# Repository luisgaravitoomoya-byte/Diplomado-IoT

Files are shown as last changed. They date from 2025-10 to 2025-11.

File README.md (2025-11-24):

Este repositorio contiene el firmware para el microPython, los scripts de backend de python y la base de datos
para desarrollar un dispositivo wearable para detectar caidas y geolocalizar a personas mayores.
Tambien se presenta el modelo 3D usado para la carcasa del proyecto de un archivo solidworks, el archivo para la placa PCB y un PDF que muestra las pruebas que se realizaron para el proyecto.

El proyecto opera bajo una arquitectura de Edge Computing y Nube segura.
Los componentes requeridos son:
Raspberry Pi Pico W: Adquisición de sensores, procesamiento de algoritmos y gestion de Wi-Fi.
Sensor MPU-6050: Sensor dedicado a la deteccion de caidas. Usado en el algoritmo hibrido.
Modulo GPS NEO-M8L: Modulo usado para la geolocalizacion, ubicacion en tiempo real y la geocerca.

Respecto a servicios externos en la web es necesario tener una cuenta en HiveMQ, MongoDB, Ubidots,Make y Telegram.

Para el firmware de la Raspberry Pi Pico W se requiere que sea MicroPython. 

Las librerias necesarias que tienen que instalar son:
umqtt.simple.py: Cliente MQTT para la comunicacion con HiveMQ.
urequests.py: Para peticiones HTTP a Ubidots, Make y Telegram.
ntptime.py: Necesario para la sincronizacion horaria, con esto se realiza la conexion SSL/TLS.
mpu6050.py: Driver de la libreria para poder leer el sensor dedicado a las caidas.
micropyGPS.py: Driver de la libreria para el modulo GPS.

En la imagen llamada circuito se puede ver las conexiones de la raspberry pi pico w con los sensores.

Cambios importantes en el main.py
Se tienen que actualizar las credenciales de cada persona. 
Como ser el nombre de la red y su contrasena: WIFI_SSID y WIFI_PASSWORD
Las credenciales de HiveMQ: BROKER_HOST, MQTT_USERNAME, MQTT_PASSWORD
Las credenciales de Ubidots: UBIDOTS_TOKEN
La URL del webhook de Make: MAKE_WEBHOOK_URL
Las credenciales de Telegram: TELEGRAM_BOT_TOKEN y TELEGRAM_CHAT_ID
La configuracion de las coordenadas de la geocerca: HOME_LAT y HOME_LON

Para los scripts de Python de la Pc que son necesarios para la base de datos es necesario instalar las librerias para el suscriptor:
pip install paho-mqtt pymongo pandas

En MongoDb hay que configurar el acceso a la red, esto se realiza asegurando que el acceso este abierto mediante la siguiente IP: 0.0.0.0/0

Actualizar el MONGO_URI de ambos scripts de python.

De igual manera se presenta los planos de los modelos 3D

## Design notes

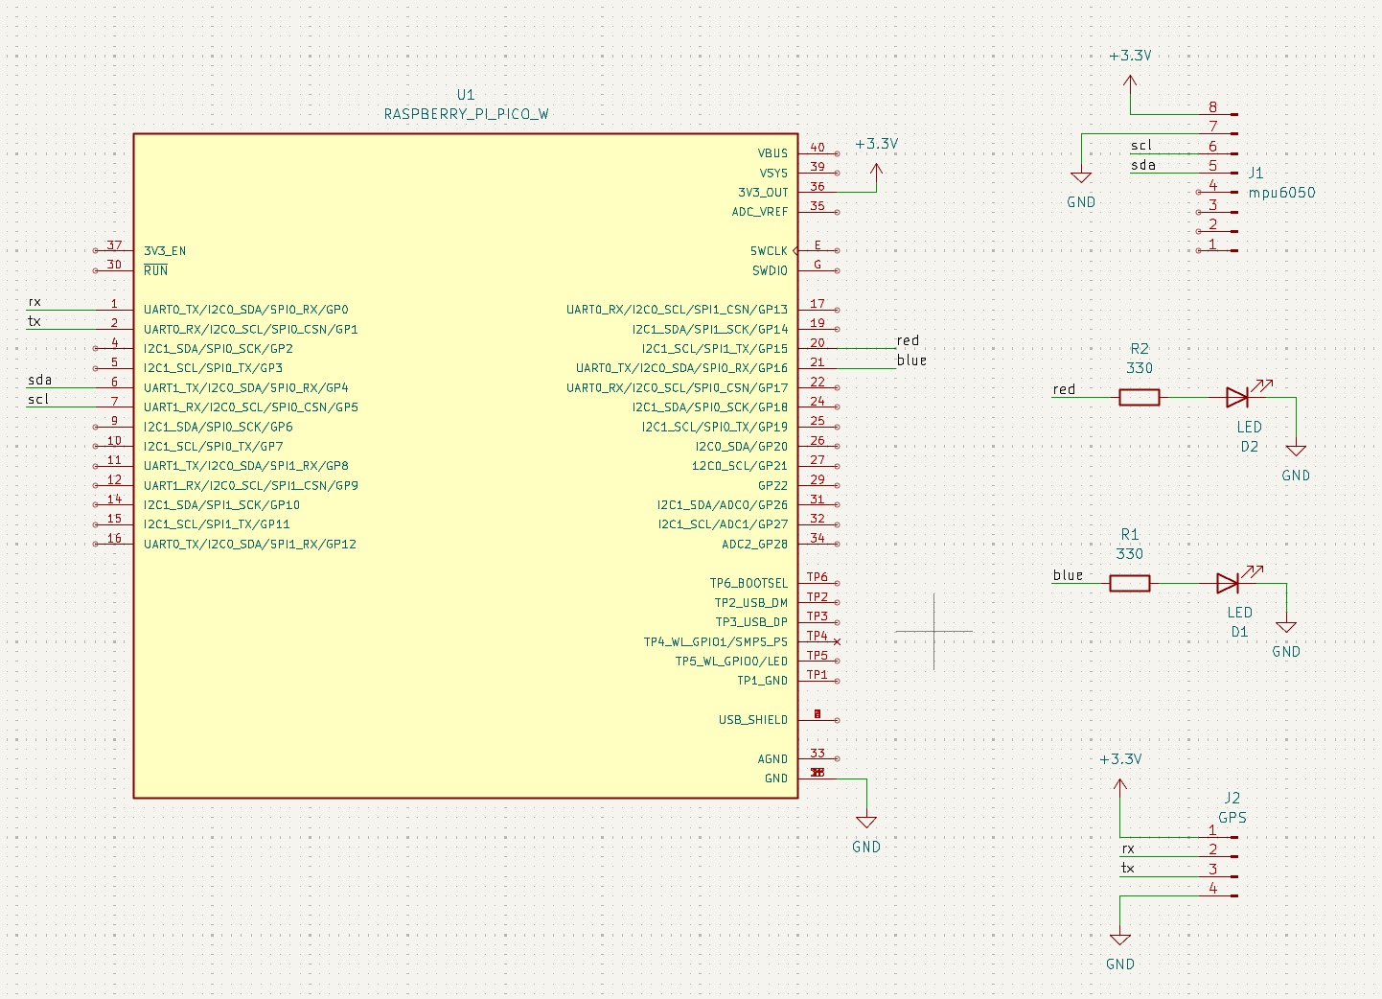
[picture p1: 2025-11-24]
Circuito.jpeg

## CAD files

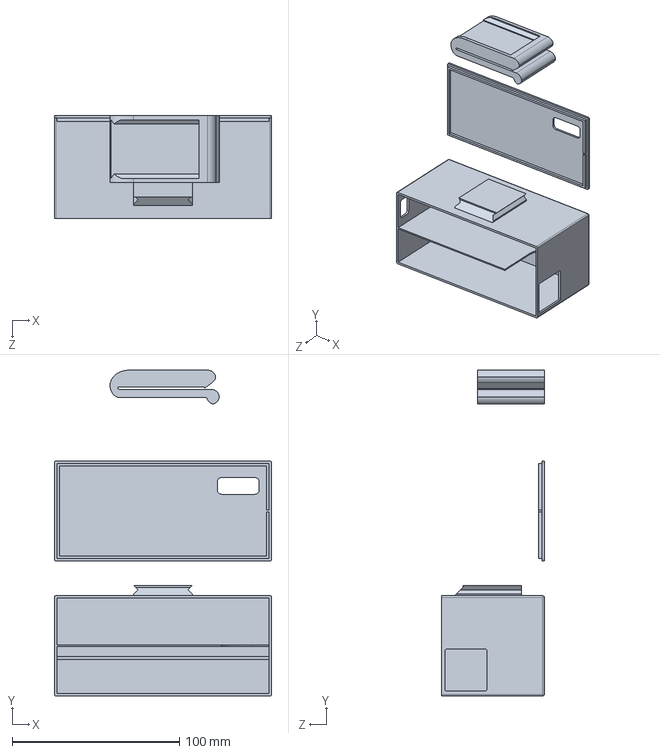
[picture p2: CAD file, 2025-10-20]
Wearable diplomado.SLDPRT
130.0 x 195.0 x 61.5 mm

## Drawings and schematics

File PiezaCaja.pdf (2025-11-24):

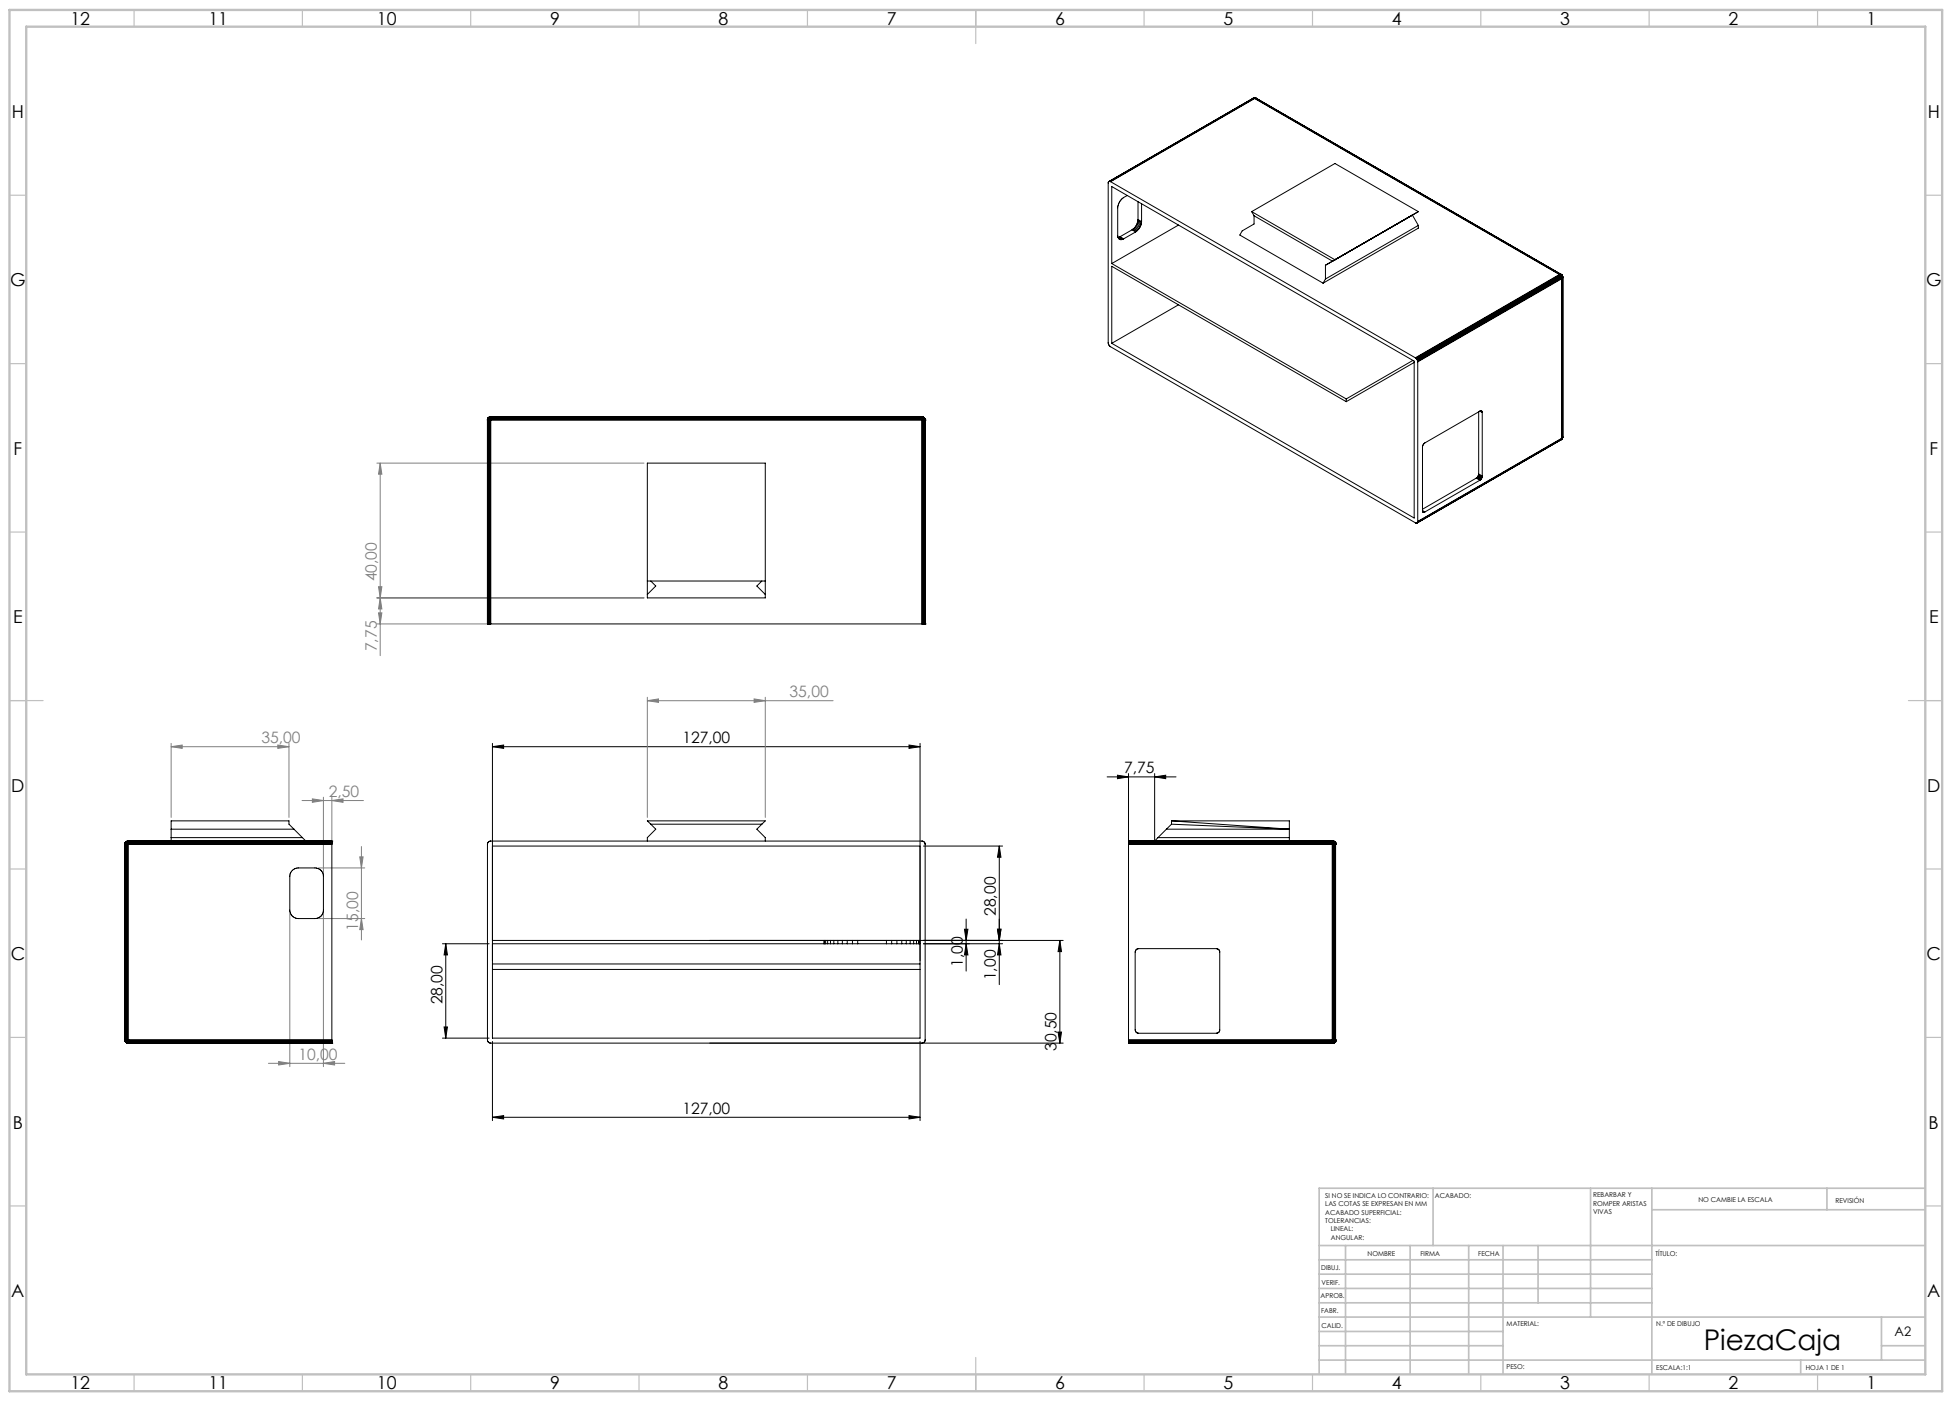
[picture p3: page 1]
ESCALA:1:1; HOJA 1 DE 1

SI NO SE INDICA LO CONTRARIO: LAS COTAS SE EXPRESAN EN MM ACABADO SUPERFICIAL: TOLERANCIAS: LINEAL: ANGULAR: | ACABADO: | REBARBAR Y ROMPER ARISTAS VIVAS | NO CAMBIE LA ESCALA | REVISIÓN

NOMBRE | FIRMA | FECHA | | | | TÍTULO:

DIBUJ.
VERIF.
APROB.
FABR.
CALID. | | | | MATERIAL: | N.º DE DIBUJO PiezaCaja | A2

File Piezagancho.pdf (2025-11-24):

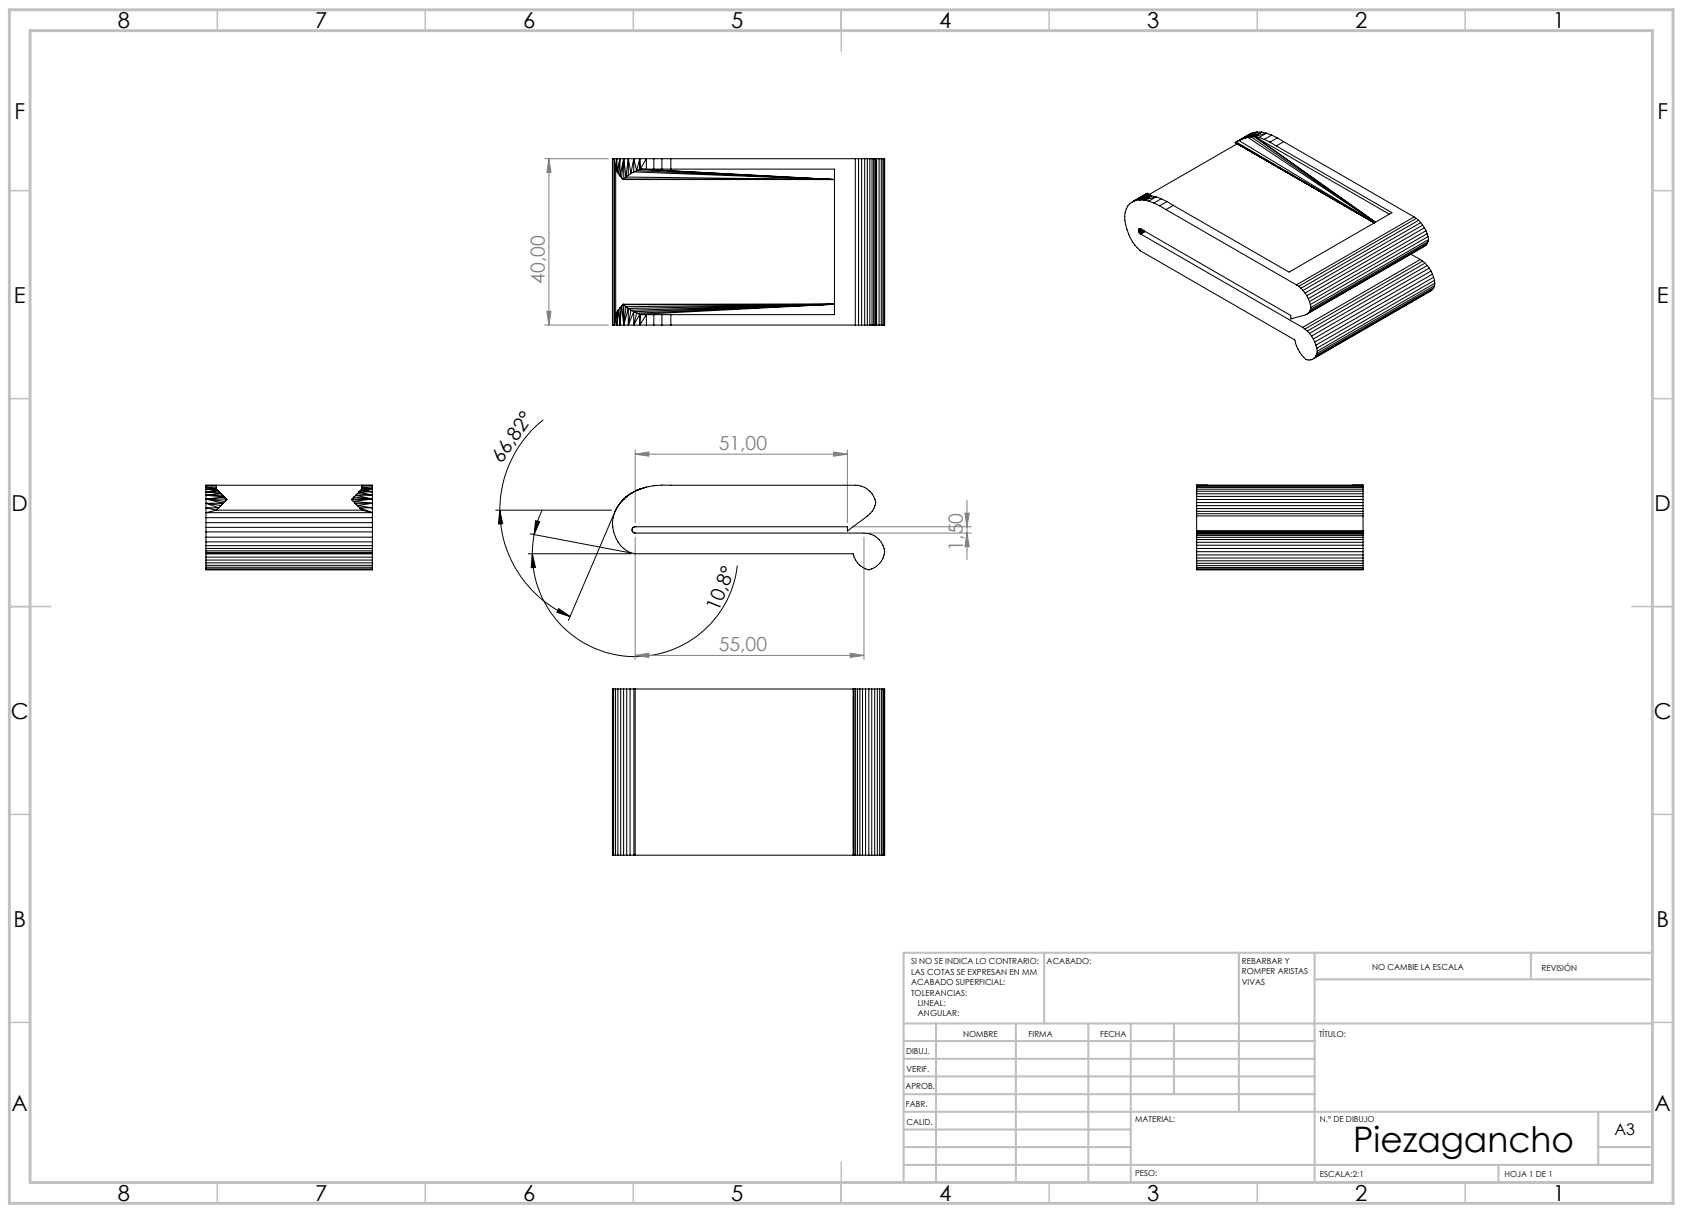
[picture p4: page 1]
ACABADO:; REBARBAR Y; ROMPER ARISTAS; NO CAMBIE LA ESCALA; REVISIÓN; ESCALA:2:1; HOJA 1 DE 1

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

NOMBRE | FIRMA | FECHA | | | | TÍTULO:

DIBUJ.
VERIF.
APROB.
FABR.
CALID. | | | | MATERIAL: | N.º DE DIBUJO Piezagancho | A3

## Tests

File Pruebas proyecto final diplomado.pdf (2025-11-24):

Registro de Pruebas Experimentales del Algoritmo Anticaídas

Este registro documenta el protocolo de validación y los resultados de las 100 caídas reales simuladas y 100 actividades cotidianas para evaluar la eficacia del algoritmo híbrido de detección de caídas, ejecutado en la Raspberry Pi Pico W.

Protocolo de Pruebas

El protocolo fue diseñado para simular escenarios de alto riesgo en la población objetivo (adultos mayores) y diferenciar caídas reales de movimientos cotidianos bruscos.

Las caídas reales simuladas fueron caídas controladas en distintas direcciones como ser hacia adelante, atrás o lateral. Le pondremos la etiqueta de CAÍDA.

Las actividades cotidianas son las acciones que uno realiza de manera normal como sentarse abruptamente, trotar, movimientos acelerados o tratar de levantar objetos. La etiqueta que se le dio es de AC.

El algoritmo de detección se consideró exitoso si se cumplía una de las siguientes condiciones:

- Verdadero positivo si hubiera una detección de CAÍDA en una simulación real.
- Verdadero negativo si hubiera una detección de NO CAÍDA en una actividad cotidiana (AC).

Las métricas críticas obtenidas son:

- Falso Negativo (FN): Caída real no detectada (4 eventos).
- Falso Positivo (FP): Alarma activada durante una AC (7 eventos).

Resultados

La siguiente tabla muestra un registro de las 100 pruebas de caídas como de actividades cotidianas.

No. | Escenario | Tiempo (ms) | Impacto Pico (G) | Algoritmo Detectó | Resultado Final

Caídas simuladas (1 - 100)

1 | Caída Lateral | 120 | 1.85 | SÍ | VP
2 | Caída | 150 | 2.51 | SÍ | VP

| Frontal
3 | Caída Trasera | 100 | 1.77 | SÍ | VP
4 | Caída Lateral | 90 | 1.62 | SÍ | VP
5 | Caída Frontal | 140 | 1.10 | SÍ | VP
6 | Caída Trasera | 105 | 0.75 | NO | FN (No Detectada)
7 | Caída Frontal | 130 | 1.30 | SÍ | VP
8 | Caída Lateral | 125 | 1.60 | SÍ | VP
9 | Caída Frontal | 145 | 1.95 | SÍ | VP
10 | Caída Trasera | 115 | 1.05 | SÍ | VP
11 | Caída Lateral | 110 | 1.90 | SÍ | VP
12 | Caída Frontal | 135 | 1.55 | SÍ | VP
13 | Caída Trasera | 120 | 1.80 | SÍ | VP
14 | Caída Lateral | 115 | 1.75 | SÍ | VP
15 | Caída Frontal | 100 | 1.20 | SÍ | VP
16 | Caída | 155 | 2.05 | SÍ | VP

| Trasera
17 | Caída Lateral | 130 | 1.45 | SÍ | VP
18 | Caída Frontal | 122 | 1.65 | SÍ | VP
19 | Caída Trasera | 108 | 1.15 | SÍ | VP
20 | Caída Lateral | 118 | 1.95 | SÍ | VP
21 | Caída Frontal | 142 | 1.40 | SÍ | VP
22 | Caída Trasera | 133 | 1.55 | SÍ | VP
23 | Caída Lateral | 105 | 1.18 | SÍ | VP
24 | Caída Frontal | 128 | 1.70 | SÍ | VP
25 | Caída Trasera | 112 | 1.09 | SÍ | VP
26 | Caída Lateral | 100 | 0.90 | NO | FN (No Detectada)
27 | Caída Frontal | 150 | 1.25 | SÍ | VP
28 | Caída Trasera | 110 | 1.50 | SÍ | VP
29 | Caída Lateral | 138 | 1.99 | SÍ | VP
30 | Caída | 115 | 1.60 | SÍ | VP

| Frontal
31 | Caída Trasera | 102 | 1.15 | SÍ | VP
32 | Caída Lateral | 145 | 1.40 | SÍ | VP
33 | Caída Frontal | 108 | 1.88 | SÍ | VP
34 | Caída Trasera | 130 | 1.70 | SÍ | VP
35 | Caída Lateral | 112 | 1.08 | SÍ | VP
36 | Caída Frontal | 148 | 1.99 | SÍ | VP
37 | Caída Trasera | 125 | 1.35 | SÍ | VP
38 | Caída Lateral | 104 | 1.20 | SÍ | VP
39 | Caída Frontal | 130 | 1.50 | SÍ | VP
40 | Caída Trasera | 111 | 1.65 | SÍ | VP
41 | Caída Lateral | 140 | 1.15 | SÍ | VP
42 | Caída Frontal | 120 | 1.70 | SÍ | VP
43 | Caída Trasera | 100 | 1.35 | SÍ | VP
44 | Caída | 135 | 0.95 | NO | FN (No

| Lateral | | | | Detectada)
45 | Caída Frontal | 145 | 1.99 | SÍ | VP
46 | Caída Trasera | 110 | 1.10 | SÍ | VP
47 | Caída Lateral | 120 | 0.95 | NO | FN (No Detectada)
48 | Caída Frontal | 130 | 1.70 | SÍ | VP
49 | Caída Trasera | 110 | 1.60 | SÍ | VP
50 | Caída Lateral | 105 | 1.20 | SÍ | VP
51 | Caída Frontal | 145 | 1.95 | SÍ | VP
52 | Caída Trasera | 115 | 1.05 | SÍ | VP
53 | Caída Lateral | 135 | 1.70 | SÍ | VP
54 | Caída Frontal | 11 5 | 0 1 . 2 | SÍ | VP
55 | Caída Trasera | 120 | 1.80 | SÍ | VP
56 | Caída Lateral | 115 | 1.75 | SÍ | VP
57 | Caída Frontal | 100 | 1.20 | SÍ | VP
58 | Caída | 155 | 2.05 | SÍ | VP

| Trasera
59 | Caída Lateral | 130 | 1.45 | SÍ | VP
60 | Caída Frontal | 122 | 1.65 | SÍ | VP
61 | Caída Trasera | 108 | 1.15 | SÍ | VP
62 | Caída Lateral | 118 | 1.95 | SÍ | VP
63 | Caída Frontal | 142 | 1.40 | SÍ | VP
64 | Caída Trasera | 133 | 1.55 | SÍ | VP
65 | Caída Lateral | 105 | 1.18 | SÍ | VP
66 | Caída Frontal | 128 | 1.70 | SÍ | VP
67 | Caída Trasera | 112 | 1.09 | SÍ | VP
68 | Caída Lateral | 100 | 0.90 | NO | FN (No Detectada)
69 | Caída Frontal | 150 | 1.25 | SÍ | VP
70 | Caída Trasera | 110 | 1.50 | SÍ | VP
71 | Caída Lateral | 138 | 1.99 | SÍ | VP
72 | Caída | 115 | 1.60 | SÍ | VP

| Frontal
73 | Caída Trasera | 102 | 1.15 | SÍ | VP
74 | Caída Lateral | 145 | 1.40 | SÍ | VP
75 | Caída Frontal | 108 | 1.88 | SÍ | VP
76 | Caída Trasera | 130 | 1.70 | SÍ | VP
77 | Caída Lateral | 112 | 1.08 | SÍ | VP
78 | Caída Frontal | 148 | 1.99 | SÍ | VP
79 | Caída Trasera | 125 | 1.35 | SÍ | VP
80 | Caída Lateral | 104 | 1.20 | SÍ | VP
81 | Caída Frontal | 130 | 1.50 | SÍ | VP
82 | Caída Trasera | 111 | 1.65 | SÍ | VP
83 | Caída Lateral | 140 | 1.15 | SÍ | VP
84 | Caída Frontal | 120 | 1.70 | SÍ | VP
85 | Caída Trasera | 100 | 1.35 | SÍ | VP
86 | Caída | 135 | 1.50 | SÍ | VP

| Lateral
87 | Caída Frontal | 145 | 1.99 | SÍ | VP
88 | Caída Trasera | 110 | 1.10 | SÍ | VP
89 | Caída Lateral | 120 | 1 .10 | SÍ | VP
90 | Caída Frontal | 130 | 1.70 | SÍ | VP
91 | Caída Trasera | 110 | 1.60 | SÍ | VP
92 | Caída Lateral | 105 | 1.20 | SÍ | VP
93 | Caída Frontal | 145 | 1.95 | SÍ | VP
94 | Caída Trasera | 115 | 1.05 | SÍ | VP
95 | Caída Lateral | 135 | 1.70 | SÍ | VP
96 | Caída Frontal | 110 | 0.90 | NO | FN (No Detectada)
97 | Caída Trasera | 120 | 1.80 | SÍ | VP
98 | Caída Lateral | 115 | 1.75 | SÍ | VP
99 | Caída Frontal | 100 | 1.20 | SÍ | VP
100 | Caída | 155 | 2.05 | SÍ | VP

| Trasera

Actividades cotidianas (101 - 200)

101 | AC: Sentarse Rápido | N/A | 1.35 | NO | VN
102 | AC: Tropezón Leve | 80 | 1.10 | NO | VN
103 | AC: Agacharse | N/A | 0.95 | NO | VN
104 | AC: Sentarse Brusco | N/A | 1.25 | NO | VN
105 | AC: Correr/Fren ar | N/A | 2.15 | SÍ | FP (Falsa Alarma)
106 | AC: Toser Fuerte | N/A | 1.08 | NO | VN
107 | AC: Levantar Objeto | N/A | 0.75 | NO | VN
108 | AC: Sentarse Brusco | N/A | 1.15 | NO | VN
109 | AC: Agacharse | N/A | 0.88 | NO | VN
110 | AC: Toser Fuerte | N/A | 1.20 | NO | VN

111 | A C: Trote Ligero | N/A | 1.25 | NO | VN
112 | A C: Agacharse | N/A | 0.65 | NO | VN
113 | A C: Correr/Fren ar | N/A | 1.30 | NO | VN
114 | A C: Levantar Objeto | N/A | 0.70 | NO | VN
115 | A C: Sentarse Rápido | N/A | 1.30 | NO | VN
116 | A C: Tropezón Leve | 70 | 1.05 | NO | VN
117 | A C: Agacharse | N/A | 0.85 | NO | VN
118 | A C: Sentarse Brusco | N/A | 1.45 | SÍ | FP (Falsa Alarma)
119 | A C: Correr/Fren ar | N/A | 2.50 | SÍ | FP (Falsa Alarma)
120 | A C: Toser Fuerte | N/A | 1.12 | NO | VN
121 | A C: Levantar Objeto | N/A | 0.60 | NO | VN
122 | A C: Sentarse | N/A | 1.10 | NO | VN

| Brusco
123 | A C: Agacharse | N/A | 0.80 | NO | VN
124 | A C: Toser Fuerte | N/A | 1.05 | NO | VN
125 | A C: Sentarse Rápido | N/A | 1.00 | NO | VN
126 | A C: Tropezón Leve | 65 | 1.20 | NO | VN
127 | A C: Agacharse | N/A | 0.90 | NO | VN
128 | A C: Sentarse Brusco | N/A | 0.85 | NO | VN
129 | A C: Correr/Fren ar | N/A | 1.08 | NO | VN
130 | A C: Toser Fuerte | N/A | 1.00 | NO | VN
131 | A C: Levantar Objeto | N/A | 0.70 | NO | VN
132 | A C: Sentarse Brusco | N/A | 1.18 | NO | VN
133 | A C: Agacharse | N/A | 0.88 | NO | VN
134 | A C: Toser | N/A | 1.25 | NO | VN

| Fuerte
135 | A C: Sentarse Rápido | N/A | 1.30 | NO | VN
136 | A C: Tropezón Leve | 75 | 1.15 | NO | VN
137 | A C: Agacharse | N/A | 0.70 | NO | VN
138 | A C: Sentarse Brusco | N/A | 1.40 | SÍ | FP (Falsa Alarma)
139 | A C: Correr/Fren ar | N/A | 1.20 | NO | VN
140 | A C: Toser Fuerte | N/A | 1.05 | NO | VN
141 | A C: Levantar Objeto | N/A | 0.65 | NO | VN
142 | A C: Sentarse Brusco | N/A | 1.20 | NO | VN
143 | A C: Agacharse | N/A | 0.80 | NO | VN
144 | A C: Toser Fuerte | N/A | 1.35 | NO | VN
145 | A C: Sentarse Rápido | N/A | 1.50 | SÍ | FP (Falsa Alarma)

146 | A C: Tropezón Leve | 85 | 1.10 | NO | VN
147 | A C: Agacharse | N/A | 0.95 | NO | VN
148 | A C: Sentarse Brusco | N/A | 1.28 | NO | VN
149 | A C: Correr/Fren ar | N/A | 0.65 | NO | VN
150 | A C: Toser Fuerte | N/A | 1.18 | NO | VN
151 | A C: Levantar Objeto | N/A | 0.55 | NO | VN
152 | A C: Sentarse Brusco | N/A | 1.12 | NO | VN
153 | A C: Agacharse | N/A | 0.85 | NO | VN
154 | A C: Toser Fuerte | N/A | 1.30 | NO | VN
155 | A C: Sentarse Rápido | N/A | 1.55 | SÍ | FP (Falsa Alarma)
156 | A C: Tropezón Leve | 90 | 1.25 | NO | VN
157 | A C: Agacharse | N/A | 0.75 | NO | VN

158 | A C: Sentarse Brusco | N/A | 1.12 | NO | VN
159 | A C: Correr/Fren ar | N/A | 0.9 | NO | VN
160 | A C: Toser Fuerte | N/A | 1.10 | NO | VN
161 | A C: Levantar Objeto | N/A | 0.65 | NO | VN
162 | A C: Sentarse Brusco | N/A | 1.22 | NO | VN
163 | A C: Agacharse | N/A | 0.88 | NO | VN
164 | A C: Toser Fuerte | N/A | 1.45 | NO | VN
165 | A C: Sentarse Rápido | N/A | 1.17 | NO | VN
166 | A C: Tropezón Leve | 80 | 1.20 | NO | VN
167 | A C: Agacharse | N/A | 0.72 | NO | VN
168 | A C: Sentarse Brusco | N/A | 1.05 | NO | VN
169 | A C: Correr/Fren | N/A | 0.95 | NO | VN

| ar
170 | A C: Toser Fuerte | N/A | 1.05 | NO | VN
171 | A C: Levantar Objeto | N/A | 0.50 | NO | VN
172 | A C: Sentarse Brusco | N/A | 1.10 | NO | VN
173 | A C: Agacharse | N/A | 0.80 | NO | VN
174 | A C: Toser Fuerte | N/A | 1.25 | NO | VN
175 | A C: Sentarse Rápido | N/A | 1.30 | NO | VN
176 | A C: Tropezón Leve | 75 | 1.18 | NO | VN
177 | A C: Agacharse | N/A | 0.90 | NO | VN
178 | A C: Sentarse Brusco | N/A | 1.55 | SÍ | FP (Falsa Alarma)
179 | A C: Correr/Fren ar | N/A | 0.85 | NO | VN
180 | A C: Toser Fuerte | N/A | 1.00 | NO | VN
181 | A C: | N/A | 0.60 | NO | VN

| Levantar Objeto
182 | A C: Sentarse Brusco | N/A | 1.25 | NO | VN
183 | A C: Agacharse | N/A | 0.75 | NO | VN
184 | A C: Toser Fuerte | N/A | 1.35 | NO | VN
185 | A C: Sentarse Rápido | N/A | 1.15 | NO | VN
186 | A C: Tropezón Leve | 85 | 1.05 | NO | VN
187 | A C: Agacharse | N/A | 0.98 | NO | VN
188 | A C: Sentarse Brusco | N/A | 1.15 | NO | VN
189 | A C: Correr/Fren ar | N/A | 1.30 | NO | VN
190 | A C: Toser Fuerte | N/A | 1.10 | NO | VN
191 | A C: Levantar Objeto | N/A | 0.55 | NO | VN
192 | A C: Sentarse Brusco | N/A | 1.20 | NO | VN

193 | A C: Agacharse | N/A | 0.70 | NO | VN
194 | A C: Toser Fuerte | N/A | 1.25 | NO | VN
195 | A C: Sentarse Rápido | N/A | 1.15 | NO | VN
196 | A C: Tropezón Leve | 80 | 1.10 | NO | VN
197 | A C: Agacharse | N/A | 0.90 | NO | VN
198 | A C: Sentarse Brusco | N/A | 1.30 | NO | VN
199 | A C: Correr/Fren ar | N/A | 1.25 | NO | VN
200 | A C: Toser Fuerte | N/A | 1.00 | NO | VN

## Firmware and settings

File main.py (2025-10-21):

from machine import UART, Pin, I2C
import utime
import network
from micropyGPS import MicropyGPS
import urequests
import math
import ujson
import usocket as socket
import ssl
import random 
import ntptime 


try:
    from umqtt.simple import MQTTClient
except ImportError:
    print("ADVERTENCIA: No se encontró la librería umqtt.simple. La alerta MQTT estará deshabilitada.")
    MQTTClient = None

try:
    from mpu6050 import MPU6050
except ImportError:
    print("ADVERTENCIA: No se encontró la librería mpu6050.py. La detección de caídas estará deshabilitada.")
    MPU6050 = None 


#CONFIGURACIÓN DEL SISTEMA Y CREDENCIALES 

#Credenciales de Wi-Fi
WIFI_SSID = "red wifi"        
WIFI_PASSWORD = "contraseña de wifi"

#Credenciales de Ubidots y Make
HTTP_SERVER = "industrial.api.ubidots.com"
UBIDOTS_DEVICE_LABEL = "gpspico"
UBIDOTS_TOKEN = "toke de ubidots" 
HTTP_PUBLISH_URL = f"http://{HTTP_SERVER}/api/v1.6/devices/{UBIDOTS_DEVICE_LABEL}"

#URL DE TU WEBHOOK DE MAKE (Geocerca)
MAKE_WEBHOOK_URL = "URL de Make" 

#Credenciales de TELEGRAM
TELEGRAM_BOT_TOKEN = "token de telegram" 
TELEGRAM_CHAT_ID = "ID del chat de telegram" 

#Configuración de Geocerca
HOME_LAT = -16.513800  
HOME_LON = -68.126000  
SAFE_RADIUS_M = 150    

#Configuración del MPU-6050
I2C_SDA_PIN = 4
I2C_SCL_PIN = 5
I2C_FREQ = 400000 

#(Detección Híbrida: Caída Libre + Alto Impacto)
MPU_THRESHOLD_G = 0.7    # Inicia la detección si Acel. < 0.7 G.
DURATION_MS = 100        # Captura caídas rápidas (100ms)
IMPACT_THRESHOLD_G = 1.05    # Mínimo impacto para confirmar la caída libre.
INTERRUPT_THRESHOLD_G = 0.85 # Hysteresis para detener la cuenta de Caída Libre.
INSTANT_IMPACT_G = 2.2     # Si Acel. > 2.2 G, activa la alerta inmediatamente.
FALL_COOLDOWN_MS = 15000   # Cooldown de 15 segundos.

# Configuración de GPS
FORCE_NEGATIVE_LAT = True 
FORCE_NEGATIVE_LON = True 
GPS_UART = UART(0, baudrate=9600, tx=Pin(0), rx=Pin(1))
my_gps = MicropyGPS(location_formatting='dd') 


#CONFIGURACIÓN DEL BROKER PRIVADO MQTT

BROKER_HOST = "URL HiveMW" 
BROKER_PORT = 8883  
MQTT_CLIENT_ID = f"pico_w_tracker_{random.getrandbits(16)}" 
MQTT_USERNAME = "usuario" 
MQTT_PASSWORD = "contraseña" 
MQTT_TOPIC_FALL = "rastreador/alerta/caida" 

#CONFIGURACIÓN DEL LED DE ESTADO
LED_PIN = Pin("LED", Pin.OUT)
LED_STATE = False


# Variables de estado globales
last_valid_lat = None
last_valid_lon = None
mpu_sensor = None 
fall_start_time = 0 
last_fall_time = 0 
last_debug_time_ms = 0
DEBUG_INTERVAL_MS = 1000
wifi_is_connected = False
mqtt_client = None 


#FUNCIONES DE UTILIDAD Y CONEXIÓN


def toggle_led():
    """Alterna el estado del LED (para el parpadeo)."""
    global LED_STATE
    LED_STATE = not LED_STATE
    LED_PIN.value(LED_STATE)

def set_led_solid_on():
    """Mantiene el LED encendido de forma fija."""
    global LED_STATE
    LED_STATE = True
    LED_PIN.value(LED_STATE)

def set_led_off():
    """Mantiene el LED apagado."""
    global LED_STATE
    LED_STATE = False
    LED_PIN.value(LED_STATE)


def set_time_ntp():
    """Sincroniza el reloj interno de la Pico W con un servidor NTP. Crucial para TLS/SSL."""
    global wifi_is_connected
    if not wifi_is_connected:
        print("[NTP] Omite la sincronización: No hay Wi-Fi.")
        return False
    
    print("[NTP] Sincronizando hora...")
    try:
        ntptime.settime()
        (year, month, day, hour, minute, second, _, _) = utime.localtime()
        print(f"[NTP] Hora sincronizada: {day}/{month}/{year} {hour}:{minute:02d}:{second:02d} UTC")
        return True
    except Exception as e:
        print(f"[NTP] Fallo al sincronizar la hora: {e}. La conexión MQTT podría fallar.")
        return False

def calculate_distance(lat1, lon1, lat2, lon2):
    """Calcula la distancia Haversine entre dos puntos GPS en metros."""
    R = 6371000 
    phi1 = math.radians(lat1)
    phi2 = math.radians(lat2)
    delta_phi = math.radians(lat2 - lat1)
    delta_lambda = math.radians(lon2 - lon1)

    a = math.sin(delta_phi / 2) * math.sin(delta_phi / 2) + \
        math.cos(phi1) * math.cos(phi2) * \
        math.sin(delta_lambda / 2) * math.sin(delta_lambda / 2)
        
    c = 2 * math.atan2(math.sqrt(a), math.sqrt(1 - a))
    
    distance_m = R * c
    return distance_m

def do_connect(ssid, password):
    """Maneja la conexión a la red Wi-Fi."""
    global wifi_is_connected
    wlan = network.WLAN(network.STA_IF)
    wlan.active(True)
    
    if wlan.isconnected():
        wifi_is_connected = True
        return True
    
    print('\n[WIFI] Conectando a la red...')
    wlan.connect(ssid, password)
    timeout = 10
    while not wlan.isconnected() and timeout > 0:
        toggle_led()
        print('.', end='')
        utime.sleep(1)
        timeout -= 1
        
    if wlan.isconnected():
        print('\n[WIFI] Conectado. IP:', wlan.ifconfig()[0])
        wifi_is_connected = True
        return True
    else:
        print('\n[WIFI] Falló la conexión.')
        wifi_is_connected = False
        return False

def initialize_mpu():
    """Inicializa el bus I2C y el sensor MPU-6050."""
    global mpu_sensor
    if MPU6050 is None: 
        print("[MPU] Inicialización omitida (librería mpu6050.py no encontrada).")
        return False
    
    print(f'[MPU] Inicializando I2C en SDA=GP{I2C_SDA_PIN}, SCL=GP{I2C_SCL_PIN}')
    try:
        i2c_bus = I2C(0, scl=Pin(I2C_SCL_PIN), sda=Pin(I2C_SDA_PIN), freq=I2C_FREQ)
        devices = i2c_bus.scan()
        if MPU6050.I2C_ADDR not in devices:
            print("ERROR: MPU-6050 no encontrado en la dirección I2C. Sistema anticaídas DESHABILITADO.")
            return False
            
        mpu_sensor = MPU6050(i2c_bus)
        _ = mpu_sensor.get_accel_data() 
        print("MPU-6050 detectado e inicializado. Sistema anticaídas ACTIVO.")
        return True
    except Exception as e:
        print(f"ERROR al inicializar MPU por excepción: {e}. Sistema anticaídas DESHABILITADO.")
        return False


#FUNCIONES DE CONEXIÓN Y ALERTA MQTT
#

def mqtt_connect_secure():
    if MQTTClient is None:
        return None

    try:
        ssl_params = {"server_hostname": BROKER_HOST}
        
        client = MQTTClient(
            client_id=MQTT_CLIENT_ID, 
            server=BROKER_HOST, 
            user=MQTT_USERNAME, 
            password=MQTT_PASSWORD,
            port=BROKER_PORT,
            ssl=True, 
            ssl_params=ssl_params, 
            keepalive=60
        )
        
        print(f"[MQTT] Intentando conectar a {BROKER_HOST}:{BROKER_PORT}...")
        connect_timeout = 10
        while connect_timeout > 0:
            try:
                client.connect()
                print(f"[MQTT] Conectado al broker seguro. ID: {MQTT_CLIENT_ID}")
                return client
            except OSError as e:
                toggle_led() 
                print('.', end='')
                utime.sleep(1)
                connect_timeout -= 1
        
        print(f"[MQTT] Falló la conexión segura al broker después de {10} segundos.")
        return None

    except Exception as e:
        print(f"[MQTT] ERROR de conexión segura al broker: {type(e).__name__}: {e}")
        return None

def send_mqtt_fall_alert(accel_magnitude, lat, lon): 
    global mqtt_client 

    if mqtt_client is None:
        print("[MQTT] Cliente no inicializado. Alerta MQTT omitida.")
        return

    try:
        payload_data = {
            "timestamp": utime.time(),
            "event": "CRITICAL_FALL",
            "impact_G": accel_magnitude,
            "device_id": MQTT_CLIENT_ID,
            "location": {"lat": lat, "lon": lon}
        }
        
        payload_json = ujson.dumps(payload_data)
        
        print("-" * 50)
        print(f"[MQTT] Intentando publicar en tópico: {MQTT_TOPIC_FALL}")
        print(f"[MQTT] Payload JSON: {payload_json}")
        print("-" * 50)
        
        mqtt_client.publish(MQTT_TOPIC_FALL, payload_json.encode('utf-8'))
        print(f"[MQTT] Publicada alerta de caída.")

    except Exception as e:
        print(f"[MQTT] Error CRÍTICO al publicar la alerta: {type(e).__name__}: {e}. Intentando reconectar...")
        
        try:
            mqtt_client.disconnect()
        except:
            pass
        mqtt_client = mqtt_connect_secure() 



#FUNCIONES DE ALERTA Y LÓGICA DE CAÍDA

def send_telegram_alert(lat, lon, is_fall_alert=False):
    """
    Envía alertas a Telegram (Geocerca o Caída).
    """
    if not do_connect(WIFI_SSID, WIFI_PASSWORD):
        print("[TELEGRAM] ERROR: No se pudo reconectar al Wi-Fi. Alerta de Telegram fallida.")
        return
        
    maps_link = f"https://www.google.com/maps?q={lat:.6f},{lon:.6f}"
    
    if is_fall_alert:
        subject = "¡ALERTA CRÍTICA: CAÍDA DETECTADA!"
        body = "Se ha detectado una caída fuerte. ¡Verifique el estado del paciente inmediatamente!"
    else:
        subject = "¡ALERTA DE GEOCERCA!"
        body = "El rastreador ha salido de la zona segura."
        
    message = (
        f"{subject}\n"
        f"{body}\n"
        f"Última Ubicación: {lat:.6f}, {lon:.6f}\n"
        f"[Ver Ubicación Exacta]({maps_link})"
    )
    
    encoded_message = message.replace('\n', '%0A').replace(' ', '%20').replace('(', '%28').replace(')', '%29')

    url_text = (
        f"https://api.telegram.org/bot{TELEGRAM_BOT_TOKEN}/sendMessage"
        f"?chat_id={TELEGRAM_CHAT_ID}"
        f"&text={encoded_message}"
        f"&parse_mode=Markdown" 
    )
    
    try:
        r_text = urequests.get(url_text)
        print(f"[TELEGRAM] Mensaje de {'CAÍDA' if is_fall_alert else 'GEOCERCA'} enviado.")
        r_text.close()
    except Exception as e:
        print(f"[TELEGRAM] Error al enviar mensaje: {e}")
        
    try:
        url_location = f"https://api.telegram.org/bot{TELEGRAM_BOT_TOKEN}/sendLocation"
        payload_loc = {"chat_id": TELEGRAM_CHAT_ID, "latitude": lat, "longitude": lon}
        r_loc = urequests.post(url_location, json=payload_loc)
        print("[TELEGRAM] Pin de ubicación enviado.")
        r_loc.close()
    except Exception as e:
        print(f"[TELEGRAM] Error al enviar Pin: {e}")


def send_alert_to_make(lat, lon, distance):
    """Dispara un Webhook HTTP POST directo a Make para notificar la alerta de Geocerca."""
    try:
        alert_payload = {
            "device_label": UBIDOTS_DEVICE_LABEL, "latitude": lat, "longitude": lon, 
            "distance_m": distance, "message": "ALERTA: RASTREADOR FUERA DE ZONA SEGURA"
        }
        response = urequests.post(MAKE_WEBHOOK_URL, json=alert_payload)
        if response.status_code == 200:
            print("[MAKE] Alerta de Geocerca enviada.")
        else:
            print(f"[MAKE] Fallo al enviar a Make. Estado: {response.status_code}")
        response.close()
    except Exception as e:
        print(f"[MAKE] Error en el Webhook a Make: {e}")


def check_for_fall(mpu_sensor):
    """
    Detecta una posible caída libre seguida de un impacto usando la aceleración total (magnitud).
    """
    global fall_start_time, last_fall_time
    
    if mpu_sensor is None: return 0.0, False

    try:
        accel = mpu_sensor.get_accel_data()
        accel_magnitude = (accel['x']**2 + accel['y']**2 + accel['z']**2)**0.5
        current_time = utime.ticks_ms()
        is_fall = False 

        if utime.ticks_diff(current_time, last_fall_time) < FALL_COOLDOWN_MS:
            return accel_magnitude, False
        
        if accel_magnitude > INSTANT_IMPACT_G:
            is_fall = True
            print("=====================================================")
            print(f"¡CAÍDA DETECTADA! (IMPACTO INSTANTÁNEO: {accel_magnitude:.2f} G)")
            print("=====================================================")
            
        elif fall_start_time != 0 and utime.ticks_diff(current_time, fall_start_time) >= DURATION_MS:
            if accel_magnitude > IMPACT_THRESHOLD_G:
                is_fall = True
                print("=====================================================")
                print(f"¡CAÍDA DETECTADA! (SEC. LIBRE + BAJO IMPACTO: {accel_magnitude:.2f} G)")
                print("=====================================================")
            else:
                print(f"[CAÍDA] Zero-G completado, pero impacto bajo ({accel_magnitude:.2f} G). Falsa alarma.")
                fall_start_time = 0
                
        elif accel_magnitude < MPU_THRESHOLD_G:
            if fall_start_time == 0:
                fall_start_time = current_time
                print(f"[CAÍDA] Zero-G iniciado ({accel_magnitude:.2f} G). Esperando {DURATION_MS}ms...")
                
        elif fall_start_time != 0 and accel_magnitude >= INTERRUPT_THRESHOLD_G:
            print(f"[CAÍDA] Zero-G INTERRUMPIDO: Acel. = {accel_magnitude:.2f} G (Debe ser < {MPU_THRESHOLD_G} G para caer).")
            fall_start_time = 0
            
        if is_fall:
            fall_start_time = 0 
            last_fall_time = current_time
            
            if last_valid_lat is not None:
                send_mqtt_fall_alert(accel_magnitude, last_valid_lat, last_valid_lon) 
            
            return accel_magnitude, True
            
    except Exception as e:
        print(f"[MPU] Error al leer MPU-6050 en el bucle: {e}")
        fall_start_time = 0 
    
    return accel_magnitude, False 


def process_and_publish(lat, lon):
    is_published = False
    

    if not do_connect(WIFI_SSID, WIFI_PASSWORD):
        print("[HTTP] Publicación y Geocerca fallida: No hay conexión Wi-Fi.")
        return False
        
    distance = calculate_distance(lat, lon, HOME_LAT, HOME_LON)
    alerta_status = 1 if distance > SAFE_RADIUS_M else 0
    
    print(f"[GEO] Distancia al hogar: {distance:.1f}m. Alerta: {'OUT' if alerta_status == 1 else 'IN'}")

    try:
        payload_data = {
            "gps": {
                "value": 1, 
                "context": {"lat": lat, "lng": lon}
            },
            "alerta_zona": alerta_status
        }
        
        headers = {
            "Content-Type": "application/json",
            "X-Auth-Token": UBIDOTS_TOKEN
        }
        
        response = urequests.post(
            HTTP_PUBLISH_URL, 
            json=payload_data, 
            headers=headers
        )
        
        if response.status_code < 400:
            print(f"[HTTP] Ubidots OK. Lat/Lon: {lat:.6f}, {lon:.6f}")
            is_published = True
        else:
            print(f"[HTTP] Error Ubidots: {response.status_code}")
            
        response.close()
            
    except Exception as e:
        print(f"[HTTP] Error de red Ubidots: {e}")
    
    if is_published and alerta_status == 1:
        send_telegram_alert(lat, lon, is_fall_alert=False)
        send_alert_to_make(lat, lon, distance)
        
    return is_published


#FUNCIÓN PRINCIPAL DE RASTREO

def main():
    
    global last_valid_lat, last_valid_lon, mpu_sensor, last_debug_time_ms, mqtt_client
    
    set_led_off()
    
    wifi_ok = do_connect(WIFI_SSID, WIFI_PASSWORD)
    
    if not wifi_ok: 
        set_led_off()
        return
    
    set_time_ntp() 
    
    mqtt_client = mqtt_connect_secure()
    mqtt_is_connected = mqtt_client is not None
    if wifi_ok and mqtt_is_connected:
        set_led_solid_on() 
        print("[LED] Ambas conexiones (Wi-Fi y MQTT) OK. LED encendido fijo.")
    else:
        set_led_off() 
        print("[LED] No se pudo establecer una o ambas conexiones principales. LED apagado.")
        
    if not initialize_mpu():
        print("[MPU] Sistema anticaídas no operativo. Procediendo solo con GPS/Geocerca.")

    print("\n" + "="*70)
    print("INICIO: Rastreo GPS con Geocerca, Caídas y MQTT")
    print("======================================================================")
    
    start_time = utime.time()
    fix_achieved = False 
    last_publish_time = 0
    PUBLISH_INTERVAL_SEC = 60 
    
    while True:
        current_time_ms = utime.ticks_ms()
        
        if mqtt_client:
            try:
                mqtt_client.check_msg() 
            except Exception as e:
                print(f"[MQTT] Fallo en el loop: {e}. Intentando reconectar...")
                try:
                    mqtt_client.disconnect()
                except:
                    pass
                mqtt_client = mqtt_connect_secure()
        
        len_data = GPS_UART.any()
        if len_data > 0:
            data = GPS_UART.read(len_data)
            for char in data: my_gps.update(chr(char))
                
            latitude = my_gps.latitude[0]
            longitude = my_gps.longitude[0]
            satellites = my_gps.satellites_in_use
            
            is_valid_position = (
                my_gps.fix_type > 0 and 
                (latitude != 0.0 or longitude != 0.0) and 
                satellites > 1
            )

            if is_valid_position:
                
                if FORCE_NEGATIVE_LAT and latitude > 0: latitude *= -1
                if FORCE_NEGATIVE_LON and longitude > 0: longitude *= -1
                
                last_valid_lat = latitude
                last_valid_lon = longitude
                
                if not fix_achieved:
                    ttff = utime.time() - start_time
                    fix_achieved = True
                    print("\n" + "#"*70)
                    print(f"      ¡FIX OBTENIDO! TTFF: {ttff} segundos.")
                    print("#"*70)
                    
            elif not fix_achieved:
                print(f"Buscando FIX... Satélites visibles: {my_gps.satellites_visible}. Segundos: {utime.time() - start_time}", end='\r')
                
        if mpu_sensor is not None:
            accel_mag, is_fall = check_for_fall(mpu_sensor)
            
            if utime.ticks_diff(current_time_ms, last_debug_time_ms) >= DEBUG_INTERVAL_MS:
                if fix_achieved: 
                    is_cooldown = utime.ticks_diff(current_time_ms, last_fall_time) < FALL_COOLDOWN_MS
                    status = "En Caída Libre" if fall_start_time != 0 else "Estable"
                    status = "COOLDOWN" if is_cooldown else status
                    
                    print(f"[MPU-DEBUG] Acel. Mag: {accel_mag:.2f} G. Estado: {status}")
                last_debug_time_ms = current_time_ms

            if is_fall:
                if last_valid_lat is not None:
                    send_telegram_alert(last_valid_lat, last_valid_lon, is_fall_alert=True)

        current_time_s = utime.time()
        if last_valid_lat is not None and (current_time_s - last_publish_time >= PUBLISH_INTERVAL_SEC):
            
            process_and_publish(last_valid_lat, last_valid_lon) 
            last_publish_time = current_time_s
            
        utime.sleep_ms(10) 

try:
    main()
except KeyboardInterrupt:
    print("\nPrograma detenido por el usuario.")
finally:
    if 'GPS_UART' in locals() and GPS_UART is not None:
        GPS_UART.deinit()
    if mqtt_client:
        try:
            mqtt_client.disconnect()
            print("[MQTT] Cliente MQTT desconectado.")
        except:
            pass
    set_led_off() 
    print("Comunicación terminada.")

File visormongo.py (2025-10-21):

import pymongo
import pandas as pd
import sys
from datetime import datetime 


MONGO_URI = "URI mongoDB"
DB_NAME = "GPS" 
COLLECTION_NAME = "fall_alerts" 


def fetch_and_display_data():
    """
    Se conecta a MongoDB, recupera todas las alertas de caída 
    y las muestra en formato de tabla usando pandas.
    """
    client = None 
    try:
        print(f"[{datetime.now().strftime('%H:%M:%S')}] Conectando a MongoDB Atlas...")
        client = pymongo.MongoClient(MONGO_URI)
        db = client[DB_NAME]
        collection = db[COLLECTION_NAME]
        
        documents = list(collection.find().sort("received_at_utc", pymongo.DESCENDING))
        
        if not documents:
            print("--------------------------------------------------")
            print("¡Base de datos vacía! No hay alertas de caída registradas.")
            print("--------------------------------------------------")
            return
            
        print(f"[{datetime.now().strftime('%H:%M:%S')}] Conexión exitosa. Se recuperaron {len(documents)} alertas.")

        data_for_df = []
        for doc in documents:
            
            local_time_data = doc.get('received_at_local', 'N/A')
            if isinstance(local_time_data, str):
                try:
                    local_time_data = datetime.fromisoformat(local_time_data)
                except ValueError:
                    local_time_data = 'ERROR_DATE'

            hora_local_str = local_time_data.strftime('%Y-%m-%d %H:%M:%S') if isinstance(local_time_data, datetime) else 'N/A'
            location = doc.get('location', {})
            lat = location.get('lat', 'N/A')
            lon = location.get('lon', 'N/A')
            data_for_df.append({
                "ID_MONGO": str(doc.get('_id')),
                "HORA_LOCAL (UTC-4)": hora_local_str,
                "DISPOSITIVO": doc.get('device_id', 'N/A'),
                "EVENTO": doc.get('event_type', 'N/A'),
                "IMPACTO (G)": f"{doc.get('impact_G', 0.0):.2f}",
                "LATITUD": f"{lat:.6f}" if isinstance(lat, float) else lat,
                "LONGITUD": f"{lon:.6f}" if isinstance(lon, float) else lon,
            })
            
        df = pd.DataFrame(data_for_df)
        
        print("\n" + "=" * 100)
        print(f"            >>> REGISTRO COMPLETO DE ALERTAS DE CAÍDA ({DB_NAME}.{COLLECTION_NAME}) <<<")
        print("=" * 100)
        display_df = df.head(20) if len(df) > 20 else df
        print(display_df.to_string(index=False))

        if len(df) > 20:
            print(f"\n... mostrando solo las primeras 20 de {len(df)} registros. Ejecuta 'df.to_string(index=False)' para ver el total si estás en un entorno interactivo.")

    except pymongo.errors.PyMongoError as e: 
        print(f"\n[ERROR CRÍTICO de MongoDB] No se pudo conectar a MongoDB. Asegúrate de que tu PC tiene acceso a internet y la IP está en la lista blanca de Atlas. Error: {e}")
        sys.exit(1)
    except Exception as e:
        print(f"\n[ERROR] Ocurrió un error inesperado: {type(e).__name__}: {e}")
    finally:
        if client:
            client.close()
            print("\n[MONGO] Conexión a MongoDB cerrada.")

if __name__ == '__main__':
    fetch_and_display_data()
